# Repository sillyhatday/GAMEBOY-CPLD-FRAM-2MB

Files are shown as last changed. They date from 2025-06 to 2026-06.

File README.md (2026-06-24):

# GAMEBOY-MBC5-CPLD-2MB

>[!WARNING]
>Current circuit board revision does not include support for the MAX7000 or ATF150x CPLD without bodges.

## Introduction:

This is my take of a CPLD based flash cart for the Gameboy.

The whole project is based from Alex's project from years back. Without that project, I would never have picked this up and spend my time figuring out how to work with CPLDs. I am not a programmer and do not claim to be. Picking up Alex's code I can see how things work with my previous knowledge of how carts operate.

The newest update has been done with the help of AI. I just wanted to get this thing done so it is off my active project list. Even though AI has helped, I have learned a little bit more about how CPLDs work because of it. In the future I'd like to use the knowledge to do another project.

Some reasons to build this project are:

	+ No need for sourcing a donor cartridge
	+ Multi MBC compatibility
	+ Cheaper to build vs a donor cart (initially not, more made, more saved)

>[!IMPORTANT]
> This project is designed with MBC5 functionality as the main priority. Compatibility with MBC1 is added on top, therefore, compatibility is not guaranteed. Super Mario Land 2 & Zelda: Link's Awakening work here, where they have issues running on a normal MBC5 chip. However, Donkey Kong Land does not work. Maybe one day I can create an MBC1 CPLD mapper.

>[!NOTE]
>For updates, see towards the end of the readme

## 🟦 Project State:

### :green_circle: Done

	- Get a cartridge that works well enough
	- Make the Altera 3032A & 3064A both work
	- Fix SRAM problems with MAX7000 and edge case MAX3000
	- Fix this readme after half updating and rage quitting. Remove V2.0 PCB pics.
	- Write draft of instructions for programming Atmel chips

### :yellow_circle: In Progress

	- Do some power tests of carts I have built so far.

### :white_circle: To Do

	- Test flashing Atmel chips in circuit
	- Design some hardware to flash Atmel chips in circuit
	- Update PCB to include solder jumper for different CPLD families.
	- Some issues with SRAM in FlashGBX with Atmel 1502A. Check hardware over & adjust SVF export settings.
	- Move FRAM chip select glue logic into software.

## 🟨 Prerequisites

	* The full components parts list and cart PCB
	* (Optional) JTAG adaptor PCB
	* Altera USB Blaster or FT232 for JTAG (cheap clones work)
	* Windows PC with Quartus II Programmer, Quartus II Web Edition or OpenOCD
	* GBxCart and related software
 	* Modified Gameboy cart shell or (optional) 3D printed Game Gear cart adaptor
	* Equipment to solder tiny SMD components
	* Skills to solder tiny SMD components reliably

## 🔌 CPLD Information

>[!TIP]
>Information on chosing a CPLD <br>
>[ALTERA PROGRAMMING GUIDE](AlteraProgrammingGuide.md) <br>
>[ATMEL PROGRAMMING GUIDE](AtmelProgrammingGuide.md) <br>
>[CPLD POWER USAGE](CartPowerUse.md) <br>

Prices vary, these are typical.

| Model | Cost x1 | Vendor |
| ----- | --- | --- |
| 3032A: | €1.16 | Aliexpress |
| 3064A: | €1.60 | Aliexpress |
| 7032S: | €1.85 | Aliexpress |
| 1504A: | €1.97 | Mouser |

Depending on the model, the AP2127K-3.3TRG1 may not be needed.

| Model | AP2127K | Jumper |
| ----- | --- | --- |
| 3032A | YES | NO |
| 3064A | YES | NO |
| 7032S | NO | YES |
| 1502A | NO | YES |

## 🟦 Parts List

### Cartridge x1

>[!IMPORTANT]
>When ordering cartridge PCBs, make sure to choose 0.8mm thickness and gold plating. <br>
>Altera MAX3000 & MAX7000 CPLDs are obselete and only found on Aliexpress. I suggest the 3032A. (MAX7000 is a relic at this point). <br>
>If ordering MAX7000, get the S version, otherwise throw your money in a fire. Eg, EPM7032S <br>
>Atmel ATF150x parts can be bought new from reputable sellers. However they are trickier to program for the average person. <br>
>Order FRAM from Aliexpress & eBay at your own risk, they are known to be ***extremely*** unreliable. <br>

| Part No. | Package | Qty |
| --- | --- | --- |
| 29F016 | TSOP48 | 1 |
| FM1808 | SOIC28 | 1 |
| CPLD* | TQFP44 | 1 |
| 74LVC1G332 | TSOP6 | 1 |
| AP2127K-3.3TRG1** | SOT23-5 | 1 |
| Cap 100nF | 0603 | 4 |
| Cap 1uF | 0603 | 2 |
| Res 10K | 0603 | 1 |

**EPM3064A, EPM3032A, EPM7064S, EPM7032S, ATF1504A or ATF1502A*
***See CPLD info*

### JTAG Adaptor

| Part No. | Qty |
| --- | --- |
| DS Lite Cart Conn | 1 |
| USB C USB4125 | 1 |
| Pin Headers | 2x5-P2.54mm |
| GG Adaptor or Shell | 1 |
| USB Blaster | 1 |

>[!TIP]
>Link to [Game Gear Adaptor](https://www.thingiverse.com/thing:5830799)

## Build Photos

cpldfram3

cpldfram1

cpldfram2

**Different CPLD** <br>
CPLDcartclose

**Original Prototype** <br>
Prototype3064A

## Update June 2026

I've picked this back up again when I found a PCB laying about. I had to wonder if AI was good enough now to help improve things. It is fortunately.

The previous update I was naive to think programming in C++ was anything like Verilog. I mean it is, but the device being programmed works so differently to other CPU based systems.

The issue that has been plaguing the 7032S & 1504A, is the save RAM functionality. Games would not save, or correctly use the cartridge as work RAM. This was on the Gameboy and cart readers. I tested this over a few carts and the first one kinda worked. It was flaky but saving, yet only on the GB and not the cart reader. There worst problem is that this problem crept into some of the 3032A and 3064A carts also.

This code refactor seems to have fixed all these problems, not only the MAX3000 but the MAX7000 also. As of now, the ATF1504 is untested. I am hopeful that it will work also. Programming those is more complex and I've since forgotten how to do it.

The smaller EPM3032A, EPM7032S & ATF1502 with 32 macro cells are now more than big enough to fit the program, no longer is it so tight. This is thanks to removing the 128KB RAM functionality, reducing the amount of registers required to address that has gained a lot of space. Additional code can be added for more functionality such as moving the FRAM gate logic into the CPLD and making it user programmable with a solder bridge on the PCB.

This is all very nice as the smaller chips tend to use less power than the larger counterparts, even though they use the same quantity of macro cells. I'll add more detailed information on the changes in its own readme.

When the Atmel part is confirmed working, I'll update the rest of the readme to walk though programming those. Ideally the PCB could use a revision to add the FRAM mode jumper and a jumper to bypass the 3.3v regulator when using the MAX7000 and ATF15xx chips. Again, I'll get to that when testing is complete.

## Firmware Versions

| Version | Status | Notes |
| --- | --- | ----- |
| V1.0.0  | Initial | Original code from Alex's blog |
| V1.0.1  | Fix | Removed internal FRAM chip select logic to lower cartridge power consumption 1 to 3% |
| V2.0.0  | Fix | Changed project compiler settings to lower cartridge power consumption 36 to 41% |
| V3.0.0  | Current | AI helper to teach me and structure code better. Use of macro cells more efficient. Logic split into smaller sections. More reliable, cleaner code, better output waveforms (I need to confirm that). |

## 🩷 Links

🔧 Driver Install: https://www.terasic.com.tw/wiki/Intel_USB_Blaster_Driver_Installation_Instructions <br>
⬇️ Driver Download: https://github.com/sudhamshu091/USB-Blaster-Driver-for-DE10-lite <br>
🖨️ Game gear Adaptor: https://www.thingiverse.com/thing:5830799 <br>
⏬ Alt Link Quartus: https://archive.org/details/quartus-iiprogrammer-and-signal-tap-ii-13.1.0.162.7z <br>
🛍️ Inside Gadgets Shop: https://shop.insidegadgets.com <br>
📎 Inside Gadgets GitHub: https://github.com/insidegadgets <br>
📷 Inside Gadgets Insta: https://www.instagram.com/inside.gadgets <br>
🖇️ Bytendo Mods GitHub: https://github.com/bytendomods <br>
🐭 Bucket Mouse: https://github.com/Bucket-Mouse <br>
🛒 Natalie Shop: https://nataliethenerd.com/ <br>
🤓 Natalie GitHub: https://github.com/natalie-lang/natalie <br>

Thanks to Xukkorz, Drew, Jamo, Alex, Deceptive Thinker, Natalie the Nerd & anyone else who I may have forgotten.

## License

This work is licensed under a Creative Commons Attribution-ShareAlike 4.0 International License. You are able to copy and redistribute the material in any medium or format, as well as remix, transform, or build upon the material for any purpose (even commercial) - but you must give appropriate credit, provide a link to the license, and indicate if any changes were made.

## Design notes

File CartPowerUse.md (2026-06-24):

## 🔌 Cartridge Power:

>[!NOTE]
>I cut the 5V plane coming from the 5v cart pin and bridged it with a 2.2Ω shunt resistor. Voltage was then measured accross the resistor to determine current used.
>These are screen captures from an emulator to show the game locations used for testing more clearly than photographs of the Gameboy screen:

First 4 caps
2nd 4 caps
Stats

## Altera EPM3064A:

| Pokemon Shin Red | Current mA V1.0 | Current mA V1.1 | Current mA V2.0 | Current mA V3.0 |
| --- | --- | --- | --- | --- |
| Intro Animation  | 30.9 | 31 | 17 | 26.4 |
| Title Screen Low | 30.3 | 30.2 | 17.6 | --- |
| Title Screen High | 35.8 | 35.7 | 23.9 | 30.9 |
| Overworld A | 32.7 | 33.1 | 21.3 | 28.4 |
| Overworld B | 30.2 | 30.5 | 18.9 | 26.1 |
| Overworld Talking | 38.7 | 38.9 | 27.6 | 33.6 |
| Pokemon Centre Nurse | 38.6 | 38.7 | 27.4 | 33.6 |
| Battle Scene | 34.8 | 34.8 | 23.3 | 30.3 |
| Pause Menu | 38.5 | 38.5 | 26.7 | 33.2 |
| Pokemon Stats | 38.7 | 38.7 | 27.1 | 33.5 |
| Average | 34.9 | 35.0 | 23.1 | 30.7 |

## Altera EPM3032A:

| Pokemon Shin Red | Current mA V1.0 | Current mA V1.1 | Current mA V2.0 | Current mA V3.0 |
| --- | --- | --- | --- | --- |
| Intro Animation | 26.4 | 25.8 | 15.9 | 17.2 |
| Title Screen Low | 25.9 | 25.1 | 15.6 | --- |
| Title Screen High | 31.8 | 30.1 | 20.9 | 23.9 |
| Overworld A | 29.0 | 28.1 | 18.5 | 20.2 |
| Overworld B | 26.5 | 25.6 | 16.4 | 17.8 |
| Overworld Talking | 34.9 | 34.1 | 24.5 | 26.2 |
| Pokemon Centre Nurse | 34.9 | 34.1 | 24.3 | 26.2 |
| Battle Scene | 31.2 | 30.3 | 20.9 | 22.7 |
| Pause Menu | 34.7 | 33.8 | 24.0 | 25.9 |
| Pokemon Stats | 35.0 | 34.1 | 24.2 | 26.4 |
| Average | 31.0 | 30.1 | 20.5 | 22.9 |

## Altera EPM7032S:

| Pokemon Shin Red | Current mA V1.0 | Current mA V1.1 | Current mA V2.0 | Current mA V3.0 |
| --- | --- | --- | --- | --- |
| Intro Animation | ---- | 34.6 | 21.8 | 20.2 |
| Title Screen Low | ---- | 34.2 | 21.6 | ---- |
| Title Screen High | ---- | 51.0 | 46.4 | 27.8 |
| Overworld A | ---- | 37.1 | 24.9 | 23.7 |
| Overworld B | ---- | 34.7 | 22.7 | 21.2 |
| Overworld Talking | ---- | 52.9 | 41.3 | 30.2 |
| Pokemon Centre Nurse | ---- | 53.0 | 41.3 | 29.7 |
| Battle Scene | ---- | 39.7 | 27.9 | 26.3 |
| Pause Menu | ---- | 42.9 | 30.9 | 29.7 |
| Pokemon Stats | ---- | 43.0 | 30.9 | 30.1 |
| Average | ---- | 42.3 | 31.0 | 26.5 |

## Atmel ATF1502A:

| Pokemon Shin Red | Current mA V1.0 | Current mA V1.1 | Current mA V2.0 | Current mA V3.0 |
| --- | --- | --- | --- | --- |
| Intro Animation | ---- | ---- | 36.8 | 40.0 |
| Title Screen Low | ---- | ---- | 36.6 | ---- |
| Title Screen High | ---- | ---- | 55.9 | 47.7 |
| Overworld A | ---- | ---- | 39.8 | ---- |
| Overworld B | ---- | ---- | 37.6 | ---- |
| Overworld Talking | ---- | ---- | 55.9 | ---- |
| Pokemon Centre Nurse | ---- | ---- | 56.0 | ---- |
| Battle Scene | ---- | ---- | 42.7 | ---- |
| Pause Menu | ---- | ---- | 45.5 | 47.9 |
| Pokemon Stats | ---- | ---- | 46.3 | 48.1 |
| Average | ---- | ---- | 46.0* | 45.9** |

>[!NOTE]
>**Buggy and strange flashing behaviour* <br>
>***RAM refuses to flash properly under sustained writes* <br>

## Summary

I did not expect the MAX3000 chips to get worse with a *better* firmware. It's not a huge difference, but it is there. I also did not expect the MAX7000 to get better! There is obviously some architecture differences that favour the older ***long*** obselete MAX7000 series.

The unfortunate data comes from the Atmel chips. I was hopeful these would be competative with the others as they are the only readily availible items. Not only have I had endless troubles getting save RAM to work properly, the amount of power used is too high. For example, a stock DMG running a stock Pokemon Blue cart uses between 44 - 60mA for the entire console...

The clear winner is the 3032A, with the lowest power use and it also being the cheapest to purchase.

Second place is a tie between the 3064A and 7032S. While the 3064A is the cheaper of the two, the 7032S is better on power. I call it a draw as the 7032S doesn't cost a lot more than the 3064A.

Last place its the 1502A with awful power draw, highest price, harder to program and still not fully working.

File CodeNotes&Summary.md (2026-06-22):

Here is some reasons that the new code works, even though it functions exactly as before. Remember that Alex wrote the code originally and this was his first time programming a CPLD.

One thing that was always flagged up in compilation was the always declaration at the top of the huge code block. It listed some and then mentioned others after that weren't declared. This was definitely causing some weird behaviours. Now each always declaration is cheated by using auto detect "always(*)".

The main bug with the original software was that everything was performed in one main block. I guess one function is how I look at it. It updates everything on every pass. This makes everything tightly coupled, increasing the amount of macro cells used and making the internal routing more complex.

This large block is split into multiple smaller blocks. The smaller blocks mean that the compiler doesn't try and stuff everything together in one giant route, it routes each block separately with less connections between them. Certain things in the code do not need other things to be updated also. There is no need to refactor everything with each state change. Enabling the RAM just needs to check some variables, there is no need to recalculate those variables again when checking. The chip-enable path becomes a simple combinational equation rather than part of a large state machine. This is at least how I think it works.

The high address logic was once again all stuffed in one block. If you look at the code, you will see that the highAddress was assigned many times in the same block. The order was critical and you could end up with the desired final state overwritten.

This being split into their own blocks allows the compiler to optimise the code independently and not try to optimise it as one. Again, using less macro cells and making a simpler route in the chip. 

The code was always monitoring addresses for 128KB RAM. There was never any want for this amount of RAM in my project, so reducing the register size down to fit just 32KB is just a no brainer. Less registers, less resources. A clean fix.

I learned a bit about wires here. I guess this can be considered like reusing code in something like C++. Instead of writing the same code over and over, you make and call a function instead.

Behind a wire, is some combinational logic, this was written out multiple times in one giant block, so the compiler used different parts of the chip to perform the same task, wasting macro cells. The wires have made only one section of the chip do the logic decoding and each block can reference that logic. No longer, each time some logic is checked, is it recalculated based on that point in time.

I don't really know what I'm talking about here. To sum up what I think is going on, the code is the same, it is just structured better to allow the compiler to use the macro cells more efficient and effectively.

Additions:

In future I'd like to add code to enable FRAM pre-charge logic, by using a spare pin to enable/disable it based on a solder bridge.

wire framMode;                                                                               // New reusable function
assign ramCE_out = framMode ? (ramCE | clk) : ramCE;         // If pin is high, do or logic, else passthrough

I'd like to add support for 4MB ROM chips. This could be also controlled with a solder bridge or be a separate program for 4MB carts. If it ends up too big for the smaller CPLDs, then removing MBC1 detection logic will gain a bit of space back. You shouldn't be running MBC1 games on an expensive 4MB based cart anyway.

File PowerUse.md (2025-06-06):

## Cartridge power use:

I cut the thin part of the 5V plane and bridged it with a 2.2Ω shunt resistor. Before that, I verified the resistor was 2.2Ω to one decimal place. Voltage was then measured accross the resistor with a multimeter set to mV with 2 decimel places.

The measurments below seem to match what Alex recorded in his blog. Bear in mind though this is for the whole cart, and Alex was using SRAM in his cart. Meaning there will be some difference and innacuracies against his results. I'm sure the difference will be negligable.

Alex's blog: https://www.insidegadgets.com/2018/08/12/building-a-2mb-mbc5-gameboy-cart-part-3-pcbs-arrived-adding-some-mbc1-support-and-troubleshooting-a-few-games/

Each cartridge and firmware revision made will be added on the end of this document.

Each reading was taken with no button inputs and the game just doing its thing. These are screen captures from an emulator to show the game locations used more clearly than photgraphs:

First 4 caps
2nd 4 caps
Stats

1mA = 2.2mV / 2.2ohm

## Firmware Revision 1.0

### Altera EPM3064A V1.0:

| Pokemon Shin Red | Resistance Ω | Vdrop | Current mA | Power mW |
| --- | --- | ----- | --- | --- |
| Intro Animation | 2.2 | 68 | 30.9 | 155 |
| Title Screen Low | 2.2 | 66.7 | 30.3 | 151.6 |
| Title Screen High | 2.2 | 78.8 | 35.8 | 179.1 |
| Overworld A | 2.2 | 72 | 32.7 | 163.6 |
| Overworld B | 2.2 | 66.4 | 30.2 | 150.9 |
| Overworld Talking | 2.2 | 85.2 | 38.7 | 193.6 |
| Pokemon Centre Nurse | 2.2 | 85 | 38.6 | 193.2 |
| Battle Scene | 2.2 | 76.5 | 34.8 | 173.9 |
| Pause Menu | 2.2 | 84.6 | 38.5 | 192.3 |
| Pokemon Stats | 2.2 | 85.1 | 38.7 | 193.4 |

**Total average current: 34.92mA**

**Total average power: 174.6mW**

### Altera EPM3032A V1.0:

| Pokemon Shin Red | Resistance Ω | Vdrop | Current mA | Power mW |
| --- | --- | ----- | --- | --- |
| Intro Animation | 2.2 | 58 | 26.4 | 131.8 |
| Title Screen Low | 2.2 | 57 | 25.9 | 129.6 |
| Title Screen High | 2.2 | 70 | 31.8 | 159.1 |
| Overworld A | 2.2 | 63.8 | 29 | 145 |
| Overworld B | 2.2 | 58.2 | 26.5 | 132.3 |
| Overworld Talking | 2.2 | 76.8 | 34.9 | 174.6 |
| Pokemon Centre Nurse | 2.2 | 76.8 | 34.9 | 174.6 |
| Battle Scene | 2.2 | 68.6 | 31.2 | 155.9 |
| Pause Menu | 2.2 | 76.3 | 34.68 | 173.4 |
| Pokemon Stats | 2.2 | 76.9 | 35 | 174.8 |

**Total average current: 31mA**

**Total average power: 155.1mW**

### Altera EPM7032S V1.0:

| Pokemon Shin Red | Resistance Ω | Vdrop | Current mA | Power mW |
| --- | --- | ----- | --- | --- |
| Intro Animation | 2.2 | -- | -- | -- |
| Title Screen Low | 2.2 | -- | -- | -- |
| Title Screen High | 2.2 | -- | -- | -- |
| Overworld A | 2.2 | -- | -- | -- |
| Overworld B | 2.2 | -- | -- | -- |
| Overworld Talking | 2.2 | -- | -- | -- |
| Pokemon Centre Nurse | 2.2 | -- | -- | -- |
| Battle Scene | 2.2 | -- | -- | -- |
| Pause Menu | 2.2 | -- | -- | -- |
| Pokemon Stats | 2.2 | -- | -- | -- |

**Total average current: xxxmA**

**Total average power: xxxmW**

### Atmel ATF1502A V1.0:

| Pokemon Shin Red | Resistance Ω | Vdrop | Current mA | Power mW |
| --- | --- | ----- | --- | --- |
| Intro Animation | 2.2 | -- | -- | -- |
| Title Screen Low | 2.2 | -- | -- | -- |
| Title Screen High | 2.2 | -- | -- | -- |
| Overworld A | 2.2 | -- | -- | -- |
| Overworld B | 2.2 | -- | -- | -- |
| Overworld Talking | 2.2 | -- | -- | -- |
| Pokemon Centre Nurse | 2.2 | -- | -- | -- |
| Battle Scene | 2.2 | -- | -- | -- |
| Pause Menu | 2.2 | -- | -- | -- |
| Pokemon Stats | 2.2 | -- | -- | -- |

**Total average current: xxxmA**

**Total average power: xxxmW**

## Firmware Revision 1.1

### Altera EPM3064A V1.1:

| Pokemon Shin Red | Resistance Ω | Vdrop | Current mA | Power mW |
| --- | --- | ----- | --- | --- |
| Intro Animation | 2.2 | 68.1 | 31 | 154.8 |
| Title Screen Low | 2.2 | 66.5 | 30.2 | 151.1 |
| Title Screen High | 2.2 | 78.6 | 35.7 | 178.6 |
| Overworld A | 2.2 | 72.8 | 33.1 | 165.5 |
| Overworld B | 2.2 | 67.1 | 30.5 | 152.5 |
| Overworld Talking | 2.2 | 85.6 | 38.9 | 194.6 |
| Pokemon Centre Nurse | 2.2 | 85.2 | 38.7 | 193.6 |
| Battle Scene | 2.2 | 76.6 | 34.8 | 174.1 |
| Pause Menu | 2.2 | 84.7 | 38.5 | 192.5 |
| Pokemon Stats | 2.2 | 85.2 | 38.73 | 193.6 |

**Total average current: 35mA**

**Total average power: 175.1mW**

### Altera EPM3032A V1.1:

| Pokemon Shin Red | Resistance Ω | Vdrop | Current mA | Power mW |
| --- | --- | ----- | --- | --- |
| Intro Animation | 2.2 | 56.7 | 25.8 | 128.9 |
| Title Screen Low | 2.2 | 55.1 | 25.1 | 125.2 |
| Title Screen High | 2.2 | 66.1 | 30.1 | 150.2 |
| Overworld A | 2.2 | 61.9 | 28.1 | 140.7 |
| Overworld B | 2.2 | 56.4 | 25.6 | 128.2 |
| Overworld Talking | 2.2 | 75 | 34.1 | 170.5 |
| Pokemon Centre Nurse | 2.2 | 74.9 | 34.1 | 170.2 |
| Battle Scene | 2.2 | 66.7 | 30.3 | 151.6 |
| Pause Menu | 2.2 | 74.4 | 33.8 | 169.1 |
| Pokemon Stats | 2.2 | 74.9 | 34.1 | 170.2 |

**Total average current: 30.1mA**

**Total average power: 150.5 mW**

### Altera EPM7032S V1.1:

| Pokemon Shin Red | Resistance Ω | Vdrop | Current mA | Power mW |
| --- | --- | ----- | --- | --- |
| Intro Animation | 2.2 | 76 | 34.6 | 172.7 |
| Title Screen Low | 2.2 | 75.2 | 34.2 | 170.9 |
| Title Screen High | 2.2 | 112 | 51 | 254.6 |
| Overworld A | 2.2 | 81.6 | 37.1 | 185.5 |
| Overworld B | 2.2 | 76.4 | 34.7 | 173.6 |
| Overworld Talking | 2.2 | 116.4 | 52.9 | 264.6 |
| Pokemon Centre Nurse | 2.2 | 116.6 | 53 | 265 |
| Battle Scene | 2.2 | 87.4 | 39.7 | 198.6 |
| Pause Menu | 2.2 | 94.3 | 42.9 | 214.3 |
| Pokemon Stats | 2.2 | 94.5 | 43 | 214.8 |

**Total average current: 42.3mA**

**Total average power: 211.5mW**

### Atmel ATF1502A V1.1:

| Pokemon Shin Red | Resistance Ω | Vdrop | Current mA | Power mW |
| --- | --- | ----- | --- | --- |
| Intro Animation | 2.2 | -- | -- | -- |
| Title Screen Low | 2.2 | -- | -- | -- |
| Title Screen High | 2.2 | -- | -- | -- |
| Overworld A | 2.2 | -- | -- | -- |
| Overworld B | 2.2 | -- | -- | -- |
| Overworld Talking | 2.2 | -- | -- | -- |
| Pokemon Centre Nurse | 2.2 | -- | -- | -- |
| Battle Scene | 2.2 | -- | -- | -- |
| Pause Menu | 2.2 | -- | -- | -- |
| Pokemon Stats | 2.2 | -- | -- | -- |

**Total average current: xxxmA**

**Total average power: xxxmW**

## Firmware Revision 2.0

### Altera EPM3064A V2.0:

| Pokemon Shin Red | Resistance Ω | Vdrop | Current mA | Power mW |
| --- | --- | ----- | --- | --- |
| Intro Animation | 2.2 | 39.5 | 17 | 89.8 |
| Title Screen Low | 2.2 | 38.7 | 17.6 | 88 |
| Title Screen High | 2.2 | 52.5 | 23.9 | 119.3 |
| Overworld A | 2.2 | 46.9 | 21.3 | 106.6 |
| Overworld B | 2.2 | 41.5 | 18.9 | 94.3 |
| Overworld Talking | 2.2 | 60.6 | 27.6 | 137.7 |
| Pokemon Centre Nurse | 2.2 | 60.2 | 27.4 | 136.8 |
| Battle Scene | 2.2 | 51.2 | 23.3 | 116.4 |
| Pause Menu | 2.2 | 58.8 | 26.7 | 133.6 |
| Pokemon Stats | 2.2 | 59.6 | 27.1 | 135.5 |

**Total average current: 23.2mA**

**Total average power: 115.8mW**

### Altera EPM3032A V2.0:

| Pokemon Shin Red | Resistance Ω | Vdrop | Current mA | Power mW |
| --- | --- | ----- | --- | --- |
| Intro Animation | 2.2 | 35 | 15.9 | 79.6 |
| Title Screen Low | 2.2 | 34.3 | 15.6 | 78 |
| Title Screen High | 2.2 | 46 | 20.9 | 104.6 |
| Overworld A | 2.2 | 40.7 | 18.5 | 92.5 |
| Overworld B | 2.2 | 36 | 16.4 | 81.8 |
| Overworld Talking | 2.2 | 53.8 | 24.5 | 122.3 |
| Pokemon Centre Nurse | 2.2 | 53.5 | 24.3 | 121.6 |
| Battle Scene | 2.2 | 45.9 | 20.9 | 104.3 |
| Pause Menu | 2.2 | 52.8 | 24 | 120 |
| Pokemon Stats | 2.2 | 53.3 | 24.2 | 121.1 |

**Total average current: 20.51mA**

**Total average power: 102.6mW**

### Altera EPM7032S V2.0:

| Pokemon Shin Red | Resistance Ω | Vdrop | Current mA | Power mW |
| --- | --- | ----- | --- | --- |
| Intro Animation | 2.2 | 48 | 21.8 | 109.1 |
| Title Screen Low | 2.2 | 47.4 | 21.6 | 107.7 |
| Title Screen High | 2.2 | 102 | 46.4 | 231.8 |
| Overworld A | 2.2 | 54.7 | 24.9 | 124.3 |
| Overworld B | 2.2 | 49.9 | 22.7 | 113.4 |
| Overworld Talking | 2.2 | 90.8 | 41.3 | 206.6 |
| Pokemon Centre Nurse | 2.2 | 90.8 | 41.3 | 206.4 |
| Battle Scene | 2.2 | 61.3 | 27.9 | 139.3 |
| Pause Menu | 2.2 | 68 | 30.9 | 154.6 |
| Pokemon Stats | 2.2 | 68 | 30.9 | 154.6 |

**Total average current: xxxmA**

**Total average power: xxxmW**

### Atmel ATF1502A V2.0?:

| Pokemon Shin Red | Resistance Ω | Vdrop | Current mA | Power mW |
| --- | --- | ----- | --- | --- |
| Intro Animation | 2.2 | 81 | 36.8 | 184.1 |
| Title Screen Low | 2.2 | 80.6 | 36.6 | 183.2 |
| Title Screen High | 2.2 | 123 | 55.9 | 279.6 |
| Overworld A | 2.2 | 87.5 | 39.8 | 198.9 |
| Overworld B | 2.2 | 82.7 | 37.6 | 188 |
| Overworld Talking | 2.2 | 123 | 55.9 | 279.6 |
| Pokemon Centre Nurse | 2.2 | 123.2 | 56 | 280 |
| Battle Scene | 2.2 | 93.9 | 42.7 | 213.4 |
| Pause Menu | 2.2 | 100 | 45.5 | 227.3 |
| Pokemon Stats | 2.2 | 101.9 | 46.3 | 231.6 |

**Total average current: 45.3mA**

**Total average power: 226.6mW**

## Averages & Percentages

| Firmware | CPLD | Current | Power | % diff vs V1.0 |
| --- | ---- | --- | --- | --- |
| v1.0 | EPM3064A | 34.92mA | 174.6mW | N/A |
| v1.0 | EPM3032A | 31mA | 155.1mW | N/A |
| v1.0 | EPM7032S | -- | -- | -- |
| v1.0 | ATF1502A | -- | -- | -- |
| v1.1 | EPM3064A | 35mA | 175.1mW | +0.23% |
| v1.1 | EPM3032A | 30.1mA | 150.5mW | -3.01% |
| v1.1 | EPM7032S | 42.3mA | 211.5mW | -- |
| v1.1 | ATF1502A | -- | -- | -- |
| v2.0 | EPM3064A | 23.2mA | 115.8mW | -33.67% |
| v2.0 | EPM3032A | 20.51mA | 102.6mW | -33.84% |
| v2.0 | EPM7032S | 31mA | 154.8mW | -- |
| v2.0? | ATF1502A | 45.3mA | 226.6mW | -- |

## Firmware Changes

### V1.0
Using Alex's code as is directly from the blog post.

### V1.1
The 3032A reduced power use as expected. The 3064A increased slightly, though a 0.5mW increase is well within margin of error. The 3032A has reduced by a larger margin, but still only 3% and within margin of error. Not what I expected.

I removed the code for the PRECHARGE logic used for FRAM chip selection. I had a feeling that the CPLD watching every clock cycle all the time was a waste of energy. It might be the case, but it's too small to really measure accurately. Likely only a few percent. Further optimising could come from stripping out the MBC1 detect logic as this cartridge is intended to be an MBC5 cartridge.

### V2.0
The CPLD macrocells are set to low power mode in the compiler. The setting is buried in menus and went unnoticed. The datasheet shows an estimate for current draw.

It seems quite accurate for an estimated value. The red marks are to help show the point of interest on the chart. It shows the 3064A using much more current than the 3032A, I think this is when you are using all macrocells in the chip. The same firmware is used across both chips and so use the same amount of macrocells.



## Further Analysis

I want to look at each measurment and see if we can make sense of it. First up...

**The Intro Animation**

So the intro animation recorded almost the lowest power usage. This is not a result I would expect having a whole bunch of animations on screen. My guess is the Gameboy is working hard, but not the cartridge. I would be willing to guess that most of the power being used is the CPLD in an idle state (I think that Alex said it was around 30mA) and the rest being the ROM chip. I'm not convinced the RAM chip is doing much of anything due to data further down the table.

So, I think the Gameboy is just streaming data out of one ROM bank for the whole intro as it does not vary much through the whole thing.

**Title Screen (Low & High)**

These two fit together nicely as it shows what is exactly going on. From memory reading about the Pokemon games, they make clever use of the cartridge RAM as work RAM. There is also a clever compression algorithm going on for sprite/graphics data. The low power draw is when the Pokemon graphic is stationary on screen, the jump in power is when the graphics slides off screen and slides in a new one. This is when the Gameboy must be shuffling data in and out of cartridge RAM from the ROM and between the Gameboy onboard RAM. The cartridge must be swapping RAM and ROM banks while doing this, causing all chips onboard to be busy bodies.

**Overworld**

I can't really explain this one. The power use varies depending on where you are located on the map. It doesn't make a whole lot of sense as things don't line up with expectations. On screen animations you may expect to cause higher power but that's not always the case. Bit of a mystery as I'd imagine everything needed to be displayed would be in RAM and while stationary, there can't be much game logic being streamed from the cart.

**Overworld Talking, Pokemon Centre Nurse, Pause Menu and Pokemon Stats**

This was a supprise but also a mystery to me. Having the lower white text box on screen always causes high cartridge power use. I could see why while loading the nex text panel and putting it on screen, but while sat stationary doesn't make sense to me. Does it have something to do with the Gameboy feature of being able to overlay a window on top of things?

**Battle Screen**

This one makes no sense to me but also does. I wouldn't expect huge power use on this screen with nothing going on, which is the case. Yet we just saw that all text boxes on screen cause power to jump, while the battle scene has exactly that going on. There are spikes in power as things change around on screen as you'd expect. Once more the Gameboy is doing a lot of work with sprites and animations.

Next I think is to try another game. One that doesn't use any of the RAM and also one with no ROM banking too. It's worth seeing how much current the CPLD uses when only tasked with ROM banking and also idling. Then finally, butcher one of my own DIY MBC5 carts to see what a 'normal' cart uses. I don't feel like butchering my original Nintendo carts.

## Depreciated Testing

### Keeping this data here as it is still useful information

Power usage vs Nintendo carts vs DIY carts.

Power use so far seems to fall inline with the EZ flash Jr. This is unfortunate, but logical as the EZ Flash uses the same PLD/FPGA technology. Overall based on measurments taken, the CPLD memory mapper looks to use 45 to 47mA more current than a regular cart. (These measurments, as you will see, are higher than the actual cartridge power measurments. This is due to inaccuracies and efficiency of the internal regulator).

These are some rough current measurements taken at the battery terminals of a Bucket Mouse DMGC and a stock DMG. These are done with the screen on max brightness and no sound. Pokemon Blue and Red were used interchangeably, as they are virtually the same game.

For projected battery life in hours [Batt], it is in reference to the Duracell 2450mAh batteries I use for Gameboy gaming. It is calculated based on mWh (11760mWh) to eliminate the voltage decrease as capacity is used. The mWh was calculated using the duracell datasheet, taking their mAh and nominal voltage. Discharge rates were ignored as these batteries have an excellent ability to maintain capacity under high loads (1C, 2C, etc). Between 1C and 0.1C is about 5% difference.

Datasheet: https://panda-bg.com/datasheet/1602-362229-Battery-Cell-AA-2450-mAh-Ni-MH-DURACELL.pdf

### DMGC

| Pokemon Blue [Nintendo] | Voltage V | Current mA | Power mW | Batt | Diff |
| --- | --- | --- | --- | --- | ---- |
| Intro Animation | 5.08V | 111mA | 564mW | 20 hours 51 minutes | 100% |
| Title Screen | 5.08V | 112-125mA | 568-635mW | 20 h  42m - 18 h 31 m | 100% |
| Overworld | 5.08V | 123mA | 624mW | 18 hours 51 minutes | 100% |
| **Pokemon Red [SillyHatMBC5]** | ----- | ----- | ----- | ----- | ----- |
| Intro Animation | 5.08V | 110mA | 559mW | 21 hours 2 minutes | 99.1% |
| Title Screen | 5.08V | 110-124mA | 559-630mW | 21 h 1 m - 18 h 40 m | 98.4-100.7% |
| Overworld | 5.08V | 123mA | 624mW | 18 hours 50 minutes | 100% |
| **Pokemon Red [CPLD]** | ----- | ----- | ----- | ----- |
| Intro Animation | 5.02V | 158mA | 793mW | 14 hours 50 minutes | 66.3% |
| Title Screen | 5.02V | 158-174mA | 793-873mW | 14 h 50 m - 13 h 28 m | 67-68.4%
| Overworld | 5.02V | 160mA | 803mW | 14 hours 39 minutes | 74.9% |

### DMG

| Pokemon Blue [Nintendo] | Voltage V | Current mA | Power mW | Batt | Diff |
| --- | --- | --- | --- | --- | --- |
| Intro Animation | 5.14V | 44mA | 226mW | 52 hours 2 minutes | 100% |
| Title Screen | 5.14V | 44-60mA | 226-308mW | 52 h 2 m - 38 h 11 m | 100% |
| Overworld | 5.14V | 47.6mA | 245mW | 48 hours 0 minutes | 100% |
| **Pokemon Red [SillyHatMBC5]** | ----- | ----- | ----- | ----- |
| Intro Animation | 5.14V | 41mA | 210mW | 56 hours 0 minutes | 107.3% |
| Title Screen | 5.13V | 42-59mA | 215-303mW | 54 h 41 m - 38 h 49 m | 105-101.6% |
| Overworld | 5.13V | 49mA | 251mW | 46 hours 51 minutes | 97.6% |
| **Pokemon Red [CPLD]** | ----- | ----- | ----- | ----- |
| Intro Animation | 5.13V | 89mA | 457mW | 25 hours 44 minutes | 67.6% |
| Title Screen | 5.10V | 89-109mA | 457-559mW | 25 h 44 m - 21 h 2 m | 67.6-58%
| Overworld | 5.10V | 91mA | 467mW | 25 hours 11 minutes | 62.4% |

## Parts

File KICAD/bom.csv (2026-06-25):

Designator | Footprint | Quantity | Value | LCSC Part #
C1, C2, C4, C6 | 0603 | 4 | 100nF
C3, C5 | 0603 | 2 | 1uF
J1 | JTAG Cart Edge Connector | 1 | Conn_01x06
R1 | 0603 | 1 | 10K
TP1 | TestPoint_Pad_D1.0mm | 1 | 5V
TP2 | TestPoint_Pad_D1.0mm | 1 | VCC
TP3 | TestPoint_Pad_D1.0mm | 1 | GND
TP4 | TestPoint_Pad_D1.0mm | 1 | TDI
TP5 | TestPoint_Pad_D1.0mm | 1 | TDO
TP6 | TestPoint_Pad_D1.0mm | 1 | TMS
TP7 | TestPoint_Pad_D1.0mm | 1 | TCK
U1 | SOIC-28W_7.5x17.9mm_P1.27mm | 1 | FM1808
U2 | TQFP-44_10x10mm_P0.8mm | 1 | 3032A
U3 | TSOP-I-48_18.4x12mm_P0.5mm | 1 | 29F016
U4 | SOT-23-5 | 1 | AP2127K
U5 | TSOP-6_1.65x3.05mm_P0.95mm | 1 | 74LVC1G332
U?1 | GameBoy_GamePak_DMG-09_P1.50mm_Edge | 1 | CartBus

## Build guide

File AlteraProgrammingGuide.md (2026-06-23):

# Programming Guide

>[!TIP]
>For the USB Blaster I prefer the larger version shown below over the smaller version. I'm not sure if it is less reliable or if it's just me being stupid. Either way, up to you.

**Smol** <br>
USB-Blaster-ALTERA-CPLDFPGA-Programmer-1-52150820

**Big** <br>
AliJTAG

>[!IMPORTANT]
>This is a rough guide and you are expected to know how to use a Windows PC, solder SMD parts, hold a pencil, etc.

Get your USB Blaster drivers installed. I used a github repo for the drivers. Install them through device manager. The links below have the details and drivers.

>[!NOTE]
>Driver Installation: https://www.terasic.com.tw/wiki/Intel_USB_Blaster_Driver_Installation_Instructions <br>
>Driver Download: https://github.com/sudhamshu091/USB-Blaster-Driver-for-DE10-lite

>[!TIP]
>Make sure you have good solder joints and that any flux is thoroughly cleaned from IC pins. The JTAG interface seems sensitive and excess flux has caused me issues trying to program.

Make sure to download the programmer software from here or source it yourself if you wish. The install is simple, just click through and wait. I have also uploaded it here:

https://archive.org/details/quartus-iiprogrammer-and-signal-tap-ii-13.1.0.162.7z

Insert your assembled cart into the JTAG adaptor using the 3D printed shim so that the cart can be inserted upside down. (The back side with the 6 cart edge pins).

>[!TIP]
>If you don’t have access to a 3D printer, you can make one by cutting around 15mm off the bottom of a cartridge shell back piece.

Launch the Quartus II Programmer software you just installed.

quartus main page

Make sure that the USB Blaster is detected and selected in Quartus. If not click “Hardware Setup…” and find it.

quartus blaster select

Once selected select the POF file for the CPLD you are using, 3064A, 3032A, 7032S or 7064S.

quartus blaster selected

If the CPLD is not yet proven, it is possible that it is already programmed from its previous life. Click “Erase” and press start. If your JTAG is connected properly and working, it should erase quickly. If problems continue, recheck JTAG connections, solder joints and flux residue. If things still do not work, then the CPLD is already programmed with JTAG disabled (requiring a professional programmer) or it is damaged.

Erasing is not required as this is done automaticall when programming. I like to do an erase on new CPLDs to prove the JTAG chain is working and the programming file isn't causing problems (wrong file, corrupted).

quartus erase

Once erased, it is worth doing a “Blank-Check” to be sure that the erase worked correctly.

quartus blank check

Finally time to program the CPLD. Check “Program/Configure” and “Verify”, then click start for the last time. It should take about 2 seconds.

>[!TIP]
>If you have any trouble, check your JTAG connections, reflow the CPLD, make sure the adaptor board is powered, clean off flux residue, check the correct POF file is selected, check the POF file is not corrupt.

quartus prog

The mapper is now programmed. You can put this stuff away for good unless you want to keep up with firmware update or program more cartridges.

Now move over to your GBxCart software and test it out.

>[!NOTE]
>Any problems in GBxCart are more likely an issue with flash chip soldering, or hidden solder between CPLD pins, than issues with the CPLD program. Any issues with programming game saves is the problem of cheap dead FRAM.

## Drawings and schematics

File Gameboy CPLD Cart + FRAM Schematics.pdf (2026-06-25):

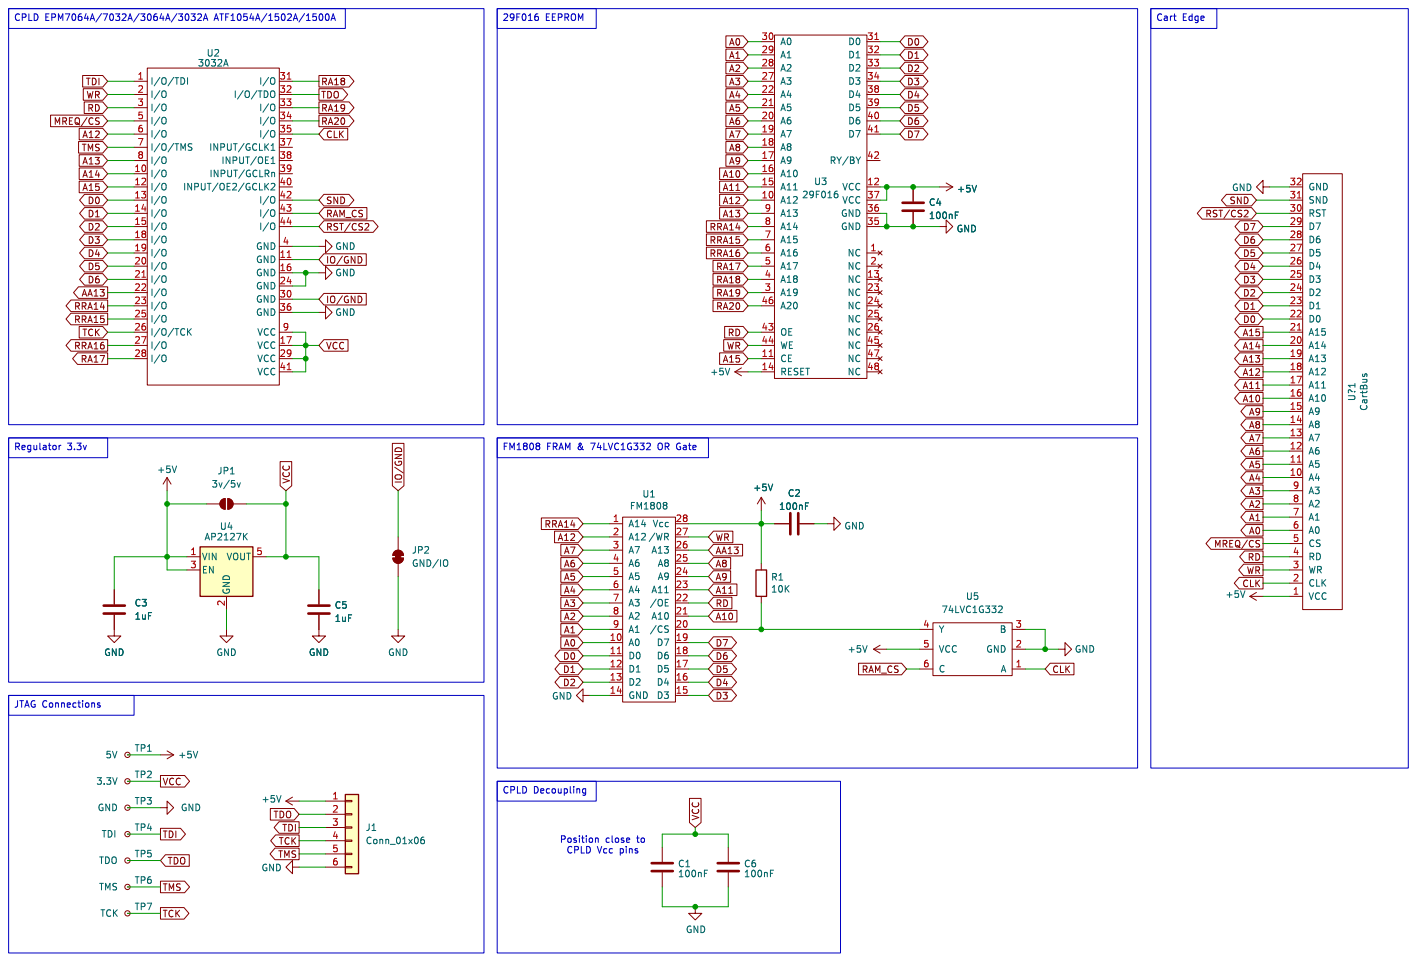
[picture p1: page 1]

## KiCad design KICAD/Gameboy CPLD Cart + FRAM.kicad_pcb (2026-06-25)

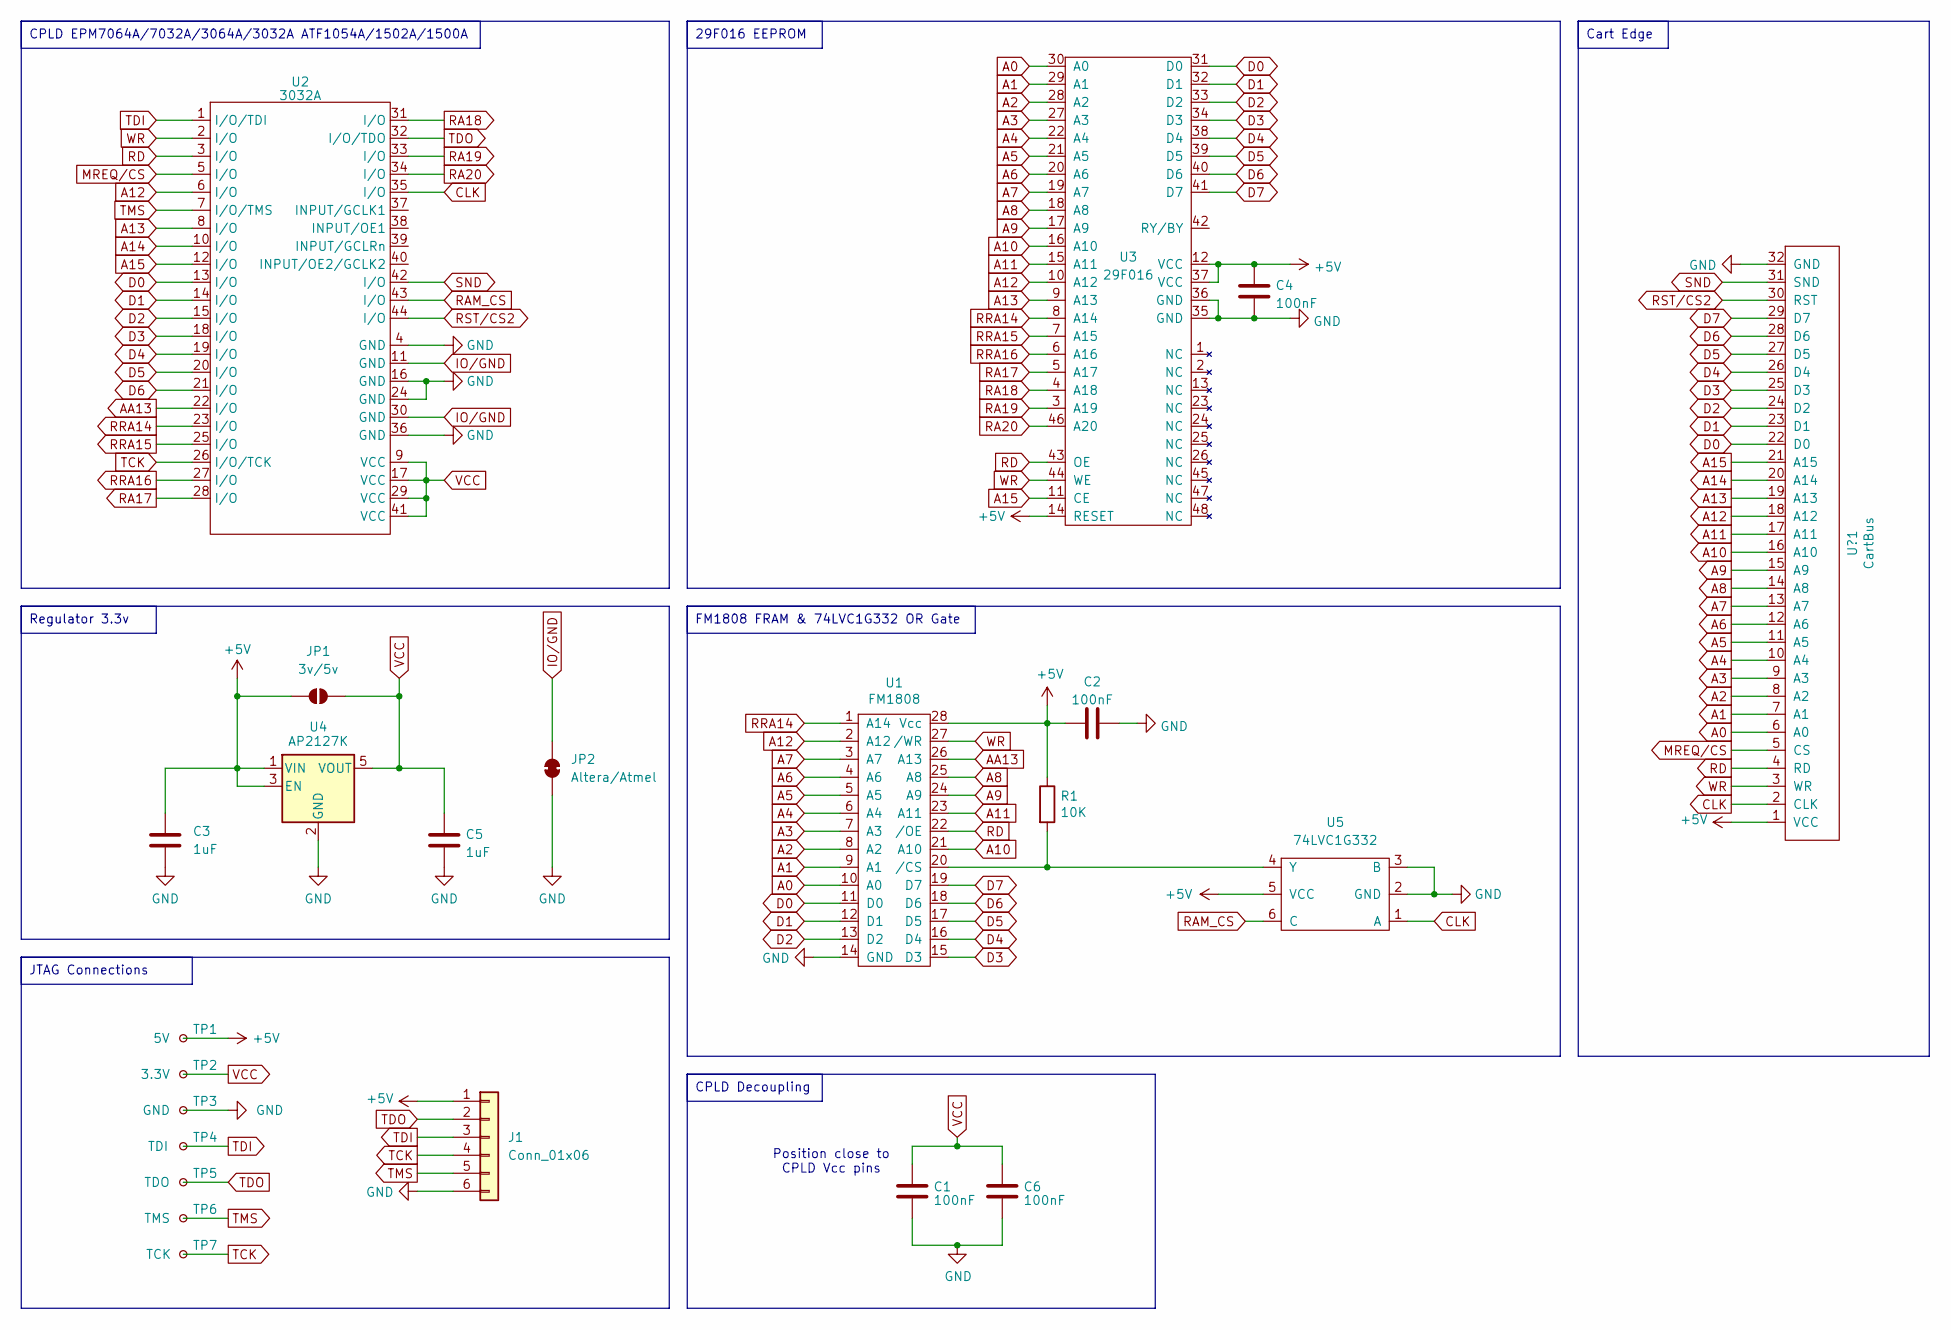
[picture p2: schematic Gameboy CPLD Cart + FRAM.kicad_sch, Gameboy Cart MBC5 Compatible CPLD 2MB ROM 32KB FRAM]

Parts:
C1, C2, C4, C6: 100nF; C_0603_1608Metric_Pad1.08x0.95mm_HandSolder
C3, C5: 1uF; C_0603_1608Metric_Pad1.08x0.95mm_HandSolder
J1: Conn_01x06; JTAG Cart Edge Connector
JP1: 3v/5v; SolderJumper-2_P1.3mm_Open_RoundedPad1.0x1.5mm
JP2: Altera/Atmel; SolderJumper-2_P1.3mm_Bridged_RoundedPad1.0x1.5mm
R1: 10K; R_0603_1608Metric_Pad0.98x0.95mm_HandSolder
TP1: 5V; TestPoint_Pad_D1.0mm
TP2: 3.3V; TestPoint_Pad_D1.0mm
TP3: GND; TestPoint_Pad_D1.0mm
TP4: TDI; TestPoint_Pad_D1.0mm
TP5: TDO; TestPoint_Pad_D1.0mm
TP6: TMS; TestPoint_Pad_D1.0mm
TP7: TCK; TestPoint_Pad_D1.0mm
U1: FM1808; SOIC-28W_7.5x17.9mm_P1.27mm
U2: 3032A; TQFP-44_10x10mm_P0.8mm
U3: 29F016; TSOP-I-48_18.4x12mm_P0.5mm
U4: AP2127K; SOT-23-5
U5: 74LVC1G332; TSOP-6_1.65x3.05mm_P0.95mm
U?1: CartBus; GameBoy_GamePak_DMG-09_P1.50mm_Edge

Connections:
+5V: C2.1, C3.1, C4.1, J1.1, JP1.1 (A), R1.1, TP1.1, U1.28 (Vcc), U3.12 (VCC), U3.14 (RESET), U3.37 (VCC~), U4.1 (VIN), U4.3 (EN), U5.5 (VCC), U?1.1 (VCC)
A0: U1.10 (A0), U3.30 (A0~), U?1.6 (A0)
A1: U1.9 (A1), U3.29 (A1), U?1.7 (A1)
A2: U1.8 (A2), U3.28 (A2), U?1.8 (A2)
A3: U1.7 (A3), U3.27 (A3), U?1.9 (A3)
A4: U1.6 (A4), U3.22 (A4), U?1.10 (A4)
A5: U1.5 (A5), U3.21 (A5), U?1.11 (A5)
A6: U1.4 (A6), U3.20 (A6), U?1.12 (A6)
A7: U1.3 (A7), U3.19 (A7), U?1.13 (A7)
A8: U1.25 (A8), U3.18 (A8), U?1.14 (A8)
A9: U1.24 (A9), U3.17 (A9), U?1.15 (A9)
A10: U1.21 (A10), U3.16 (A10), U?1.16 (A10)
A11: U1.23 (A11), U3.15 (A11), U?1.17 (A11)
A12: U1.2 (A12), U2.6 (I/O), U3.10 (A12), U?1.18 (A12)
A13: U2.8 (I/O), U3.9 (A13), U?1.19 (A13)
A14: U2.10 (I/O), U?1.20 (A14)
A15: U2.12 (I/O), U3.11 (CE), U?1.21 (A15)
AA13: U1.26 (A13), U2.22 (I/O)
CLK: U2.35 (I/O), U5.1 (A), U?1.2 (CLK~)
D0: U1.11 (D0), U2.13 (I/O), U3.31 (D0), U?1.22 (D0)
D1: U1.12 (D1), U2.14 (I/O), U3.32 (D1), U?1.23 (D1)
D2: U1.13 (D2), U2.15 (I/O), U3.33 (D2), U?1.24 (D2)
D3: U1.15 (D3), U2.18 (I/O), U3.34 (D3), U?1.25 (D3)
D4: U1.16 (D4), U2.19 (I/O), U3.38 (D4), U?1.26 (D4)
D5: U1.17 (D5), U2.20 (I/O), U3.39 (D5), U?1.27 (D5)
D6: U1.18 (D6), U2.21 (I/O), U3.40 (D6), U?1.28 (D6)
D7: U1.19 (D7), U3.41 (D7), U?1.29 (D7)
GND: C1.1, C2.2, C3.2, C4.2, C5.2, C6.1, J1.6, JP2.1 (A), TP3.1, U1.14 (GND), U2.4 (GND), U2.16 (GND), U2.24 (GND), U2.36 (GND), U3.35 (GND), U3.36 (GND), U4.2 (GND), U5.2 (GND), U5.3 (B), U?1.32 (GND)
IO/GND: JP2.2 (B), U2.11 (GND), U2.30 (GND)
MREQ/CS: U2.5 (I/O), U?1.5 (CS)
unnamed: R1.2, U1.20 (/CS), U5.4 (Y)
RA17: U2.28 (I/O), U3.5 (A17)
RA18: U2.31 (I/O), U3.4 (A18)
RA19: U2.33 (I/O), U3.3 (A19)
RA20: U2.34 (I/O), U3.46 (A20)
RAM_CS: U2.43 (I/O), U5.6 (C)
RD: U1.22 (/OE), U2.3 (I/O), U3.43 (OE~), U?1.4 (RD)
RRA14: U1.1 (A14), U2.23 (I/O), U3.8 (A14)
RRA15: U2.25 (I/O), U3.7 (A15)
RRA16: U2.27 (I/O), U3.6 (A16)
RST/CS2: U2.44 (I/O), U?1.30 (RST)
SND: U2.42 (I/O), U?1.31 (SND)
TCK: J1.4, TP7.1, U2.26 (I/O/TCK)
TDI: J1.3, TP4.1, U2.1 (I/O/TDI)
TDO: J1.2, TP5.1, U2.32 (I/O/TDO)
TMS: J1.5, TP6.1, U2.7 (I/O/TMS)
VCC: C1.2, C5.1, C6.2, JP1.2 (B), TP2.1, U2.9 (VCC), U2.17 (VCC), U2.29 (VCC), U2.41 (VCC), U4.5 (VOUT)
WR: U1.27 (/WR), U2.2 (I/O), U3.44 (WE), U?1.3 (WR)

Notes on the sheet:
CPLD Decoupling
Cart Edge
JTAG Connections
FM1808 FRAM & 74LVC1G332 OR Gate
CPLD EPM7064A/7032A/3064A/3032A ATF1054A/1502A/1500A
29F016 EEPROM
Regulator 3.3v
Position close to CPLD Vcc pins

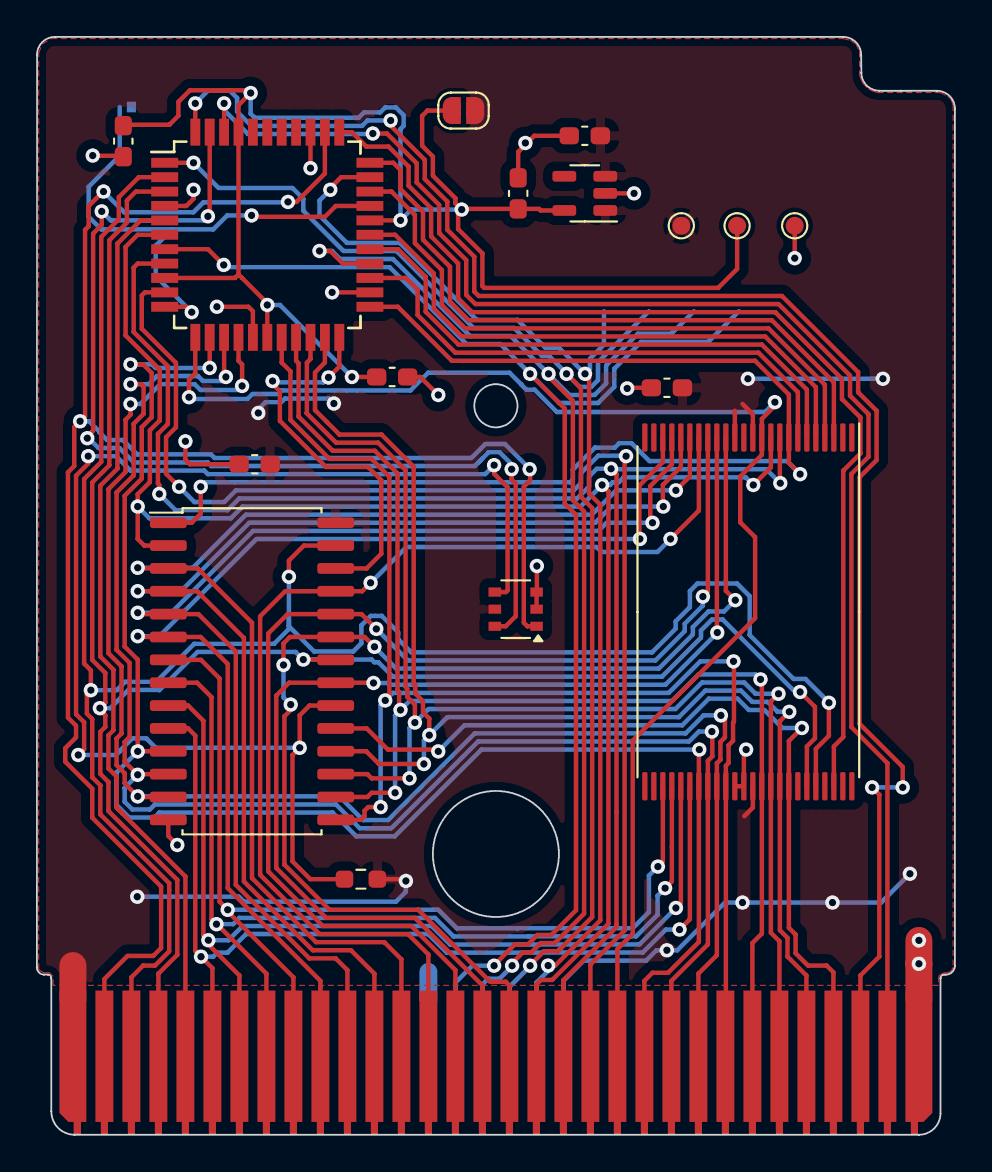
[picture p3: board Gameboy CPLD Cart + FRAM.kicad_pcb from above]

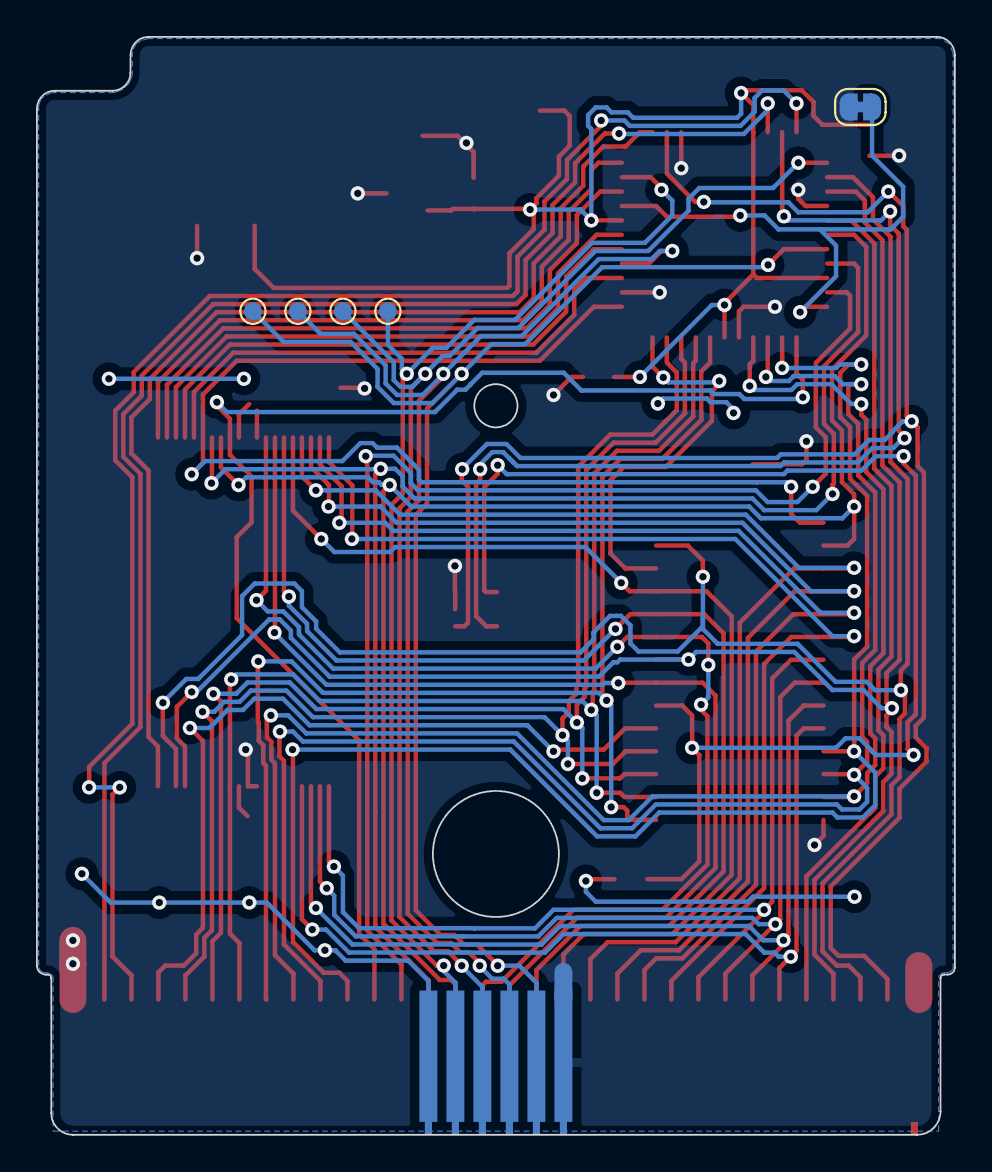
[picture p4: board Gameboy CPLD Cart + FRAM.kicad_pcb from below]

Board: 2 copper layers, 51.0 x 61.0 mm, 23 parts (6 on the bottom side), 48 nets.

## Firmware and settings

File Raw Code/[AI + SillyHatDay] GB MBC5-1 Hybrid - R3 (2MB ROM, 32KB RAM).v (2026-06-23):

module MBC5_CPLD_Mapper (
    reset,
    inputAddress,
    inputData,
    inputCE,
    inputWR,
    inputRD,
    highAddress,
    ramCE
);

// ============================================================
// Port Declarations
// ============================================================
input           reset;												// Reset from cart edge
input   [3:0]   inputAddress;   									// A15-A12 from cart edge
input   [6:0]   inputData;      									// D6-D0 from cart edge (only 7 bits needed)
input           inputCE;											// Chip select from cart edge (active low)
input           inputWR;											// Write from cart edge (active low)
input           inputRD;											// Read from cart edge (active low)

output  [7:0]   highAddress;    									// Address outputs A20-A13
output          ramCE;												// Gated chip select output

// ============================================================
// Internal Registers
// ============================================================
reg [7:0]   highAddress;											// Storage for address outputs A20-A13
reg [6:0]   romBank;												// Storage for selected ROM bank
reg [1:0]   ramBank;												// Storage for selected RAM bank
reg         ramEnabled;												// Are RAM read/writes enabled?
reg         mbc1Detect303FOn;                                       // Detected bank 0 switch, MBC1 behaviour
reg         mbc1Detected607F;										// Write detected in area MBC3/5 doesn't write to
reg         mbc3or5Locked;											// Accessed over bank 32, must be MBC3/5. (Ignoring the few 2MB MBC1 games)

// ============================================================
// Convenience wires - reusable logic blocks. Output routed to other blocks reading it.
// ============================================================
wire busActive  = (!inputRD || !inputWR);   						// Is a read or write happening? Gate address output
wire isWrite    = (!inputWR && inputRD && inputCE); 				// Is a clean write happening? Bank register write
wire isRamArea  = (inputAddress == 4'hA || inputAddress == 4'hB);	// Is address in 0xA000-BFFF window?
wire isRomLow   = (inputAddress <= 4'd3);   						// Looking at low 16KB ROM 0x0000-3FFF?
wire isRomHigh  = (inputAddress >= 4'd4 && inputAddress <= 4'd7); 	// Looking at high 16KB ROM 0x4000-7FFF?

// ============================================================
// ramCE — purely combinatorial, separate block
// ============================================================
reg ramCE;

always @ (*) begin													// Monitor everything in this block
    if (ramEnabled && isRamArea && busActive) begin					// Is RAM enabled, address in range 0x0000–1FFF & bus clear?
        ramCE = inputCE;											// If check passed, passthrough signal
    end
    else begin
        ramCE = 1'b1; 												// Set output high for off - active low
    end
end

// ============================================================
// highAddress — combinatorial, depends on address + bank regs
// ============================================================
always @ (*) begin													// Monitor everything in this block
    if (isRamArea && ramEnabled && busActive) begin					// Is RAM being accessed?
        highAddress = {6'b0, ramBank};								// Change address pins to current RAM bank value saved
    end
    else if (busActive && isRomLow) begin							// Is lower 16KB ROM being accessed?
        highAddress = 8'b0;											// Map lower 16KB bank address (turn off high address lines)
    end
    else if (busActive && isRomHigh) begin							// Is upper 16KB ROM being accessed?
        highAddress = (romBank << 1);								// Map upper 16KB banks address (bit shift to fit 7 bits into 8 correctly)
    end																// AKA align A14 with A14, else A14 would line up with A13
    else begin
        highAddress = 8'b0;											// If all else fails, just map 16KB lower bank
    end
end

// ============================================================
// Registered state — resets and bank register writes
// Triggered on control signals + address + data
// ============================================================
always @ (*) begin													// Try negedge here instead of being transparent

    if (!reset) begin
        romBank             <= 7'd1;								// Inferred latches are OK
        ramBank             <= 2'd0;								// All these updated at once when out of reset
        ramEnabled          <= 1'b0;								// <= inside transparent block is weird
        mbc1Detect303FOn    <= 1'b0;
        mbc1Detected607F    <= 1'b0;
        mbc3or5Locked       <= 1'b0;
    end
    else begin

        if ((inputAddress == 4'd0 || inputAddress == 4'd1) && isWrite) begin	// 0x0000-1FFF — RAM Enable
            ramEnabled <= (inputData[3:0] == 4'hA) ? 1'b1 : 1'b0;				// Write 0x?A to enable, anything else disables
        end

        if ((inputAddress == 4'd2 ||
            (inputAddress == 4'd3 && mbc1Detect303FOn)) && isWrite) begin		// 0x2000-3FFF — ROM Bank Number low 7 bits
            if (inputData == 7'd0) begin										// Check for a switch to bank 0, MBC1 behaviour
                romBank          <= 7'd1; 										// MBC5 allows bank 0, keep as 1, doesn't seem to be a bother
                mbc1Detect303FOn <= 1'b1;										// MBC1 detection noted
            end
            else begin
                if (inputData >= 7'd32) begin									// Is a bank switch happening above bank 32?
                    mbc3or5Locked <= 1'b1;										// If so it's MBC3 or 5, lock state to MBC5
                end
                romBank <= inputData;											// If none of the above, save data to register
            end
        end

        if ((inputAddress == 4'd4 || inputAddress == 4'd5) && isWrite) begin		// 0x4000-5FFF — RAM Bank Number
            if (!(mbc1Detect303FOn && mbc1Detected607F && !mbc3or5Locked)) begin	// Ignored if MBC1 detected and not MBC3/5
                ramBank <= inputData[1:0];											// Low two bits of inputData saved to register
            end
        end

        if ((inputAddress == 4'd6 || inputAddress == 4'd7) && isWrite) begin	 // 0x6000-7FFF — MBC1 ROM/RAM mode detection, MBC3/5 doesn't write here
            mbc1Detected607F <= 1'b1;											 // MBC1 detected, set register bit
        end

    end
end

endmodule

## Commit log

2025-05-29 Delete GerberFiles directory
    Removed V1 gerbers to tidy up
2025-05-29 Update PowerUse.md
    Large formatting update and added placeholders for v2.0 firmware
2025-05-29 Update PowerUse.md
    Updated MAX7000 series part numbers to correct ones
2025-05-29 Update PowerUse.md
    Place holders added for Atmel devices
2025-05-29 Update PowerUse.md
    Added v2 3064a power figures
2025-05-29 Update PowerUse.md
    updated average table
2025-05-30 Update PowerUse.md
    Added 3032A power figures
2025-05-30 Update PowerUse.md
    Typo fix
2025-06-01 Update README.md
    Updated readme for V2 PCB
2025-06-06 Update PowerUse.md
    added some data for 7032S and 1502A
2026-06-24 Rename PowerUse.md to ARCHIVE/PowerUseOld.md
    archived old power use stats
2026-06-24 Create CartPowerUse.md
    New power charts, mid point save
2026-06-24 Update README.md
    linked power usage doc
